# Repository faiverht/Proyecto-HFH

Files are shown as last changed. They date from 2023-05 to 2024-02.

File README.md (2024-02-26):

# Proyecto-HFH

## Avance placa primera versión:
Tarjeta de expansión de puertos análogos con conversor análogo digital MCP3424 (4 canales de 18 bits, PGA:1, 2, 4, 8), comunicación I2C dirección I2C (default): 1101

## Frontal
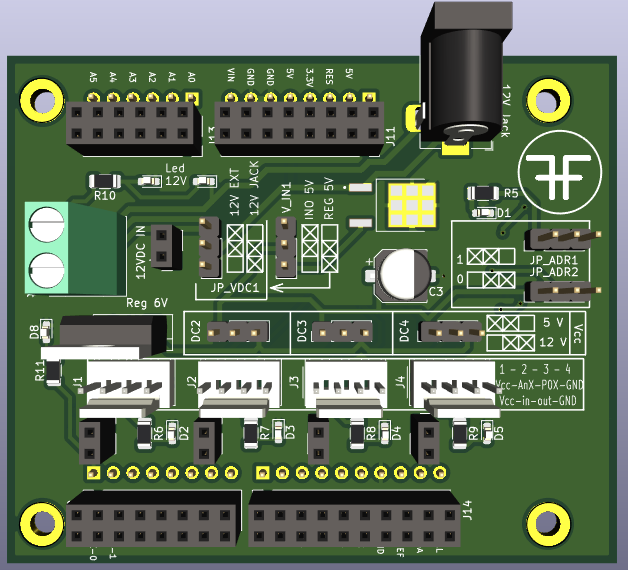
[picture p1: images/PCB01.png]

## Trasera
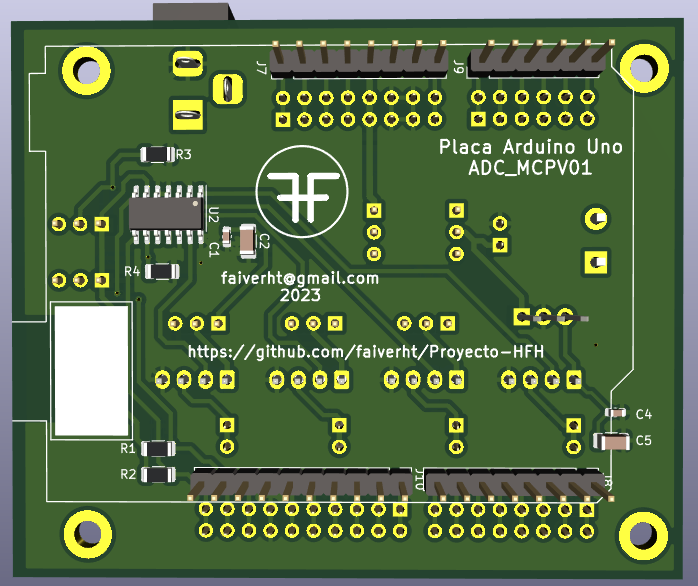
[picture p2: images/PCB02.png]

## Otras
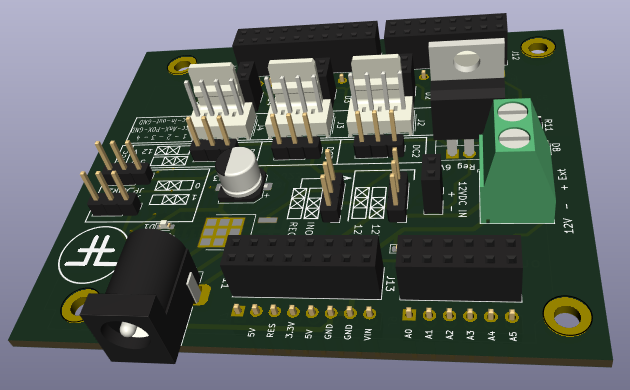
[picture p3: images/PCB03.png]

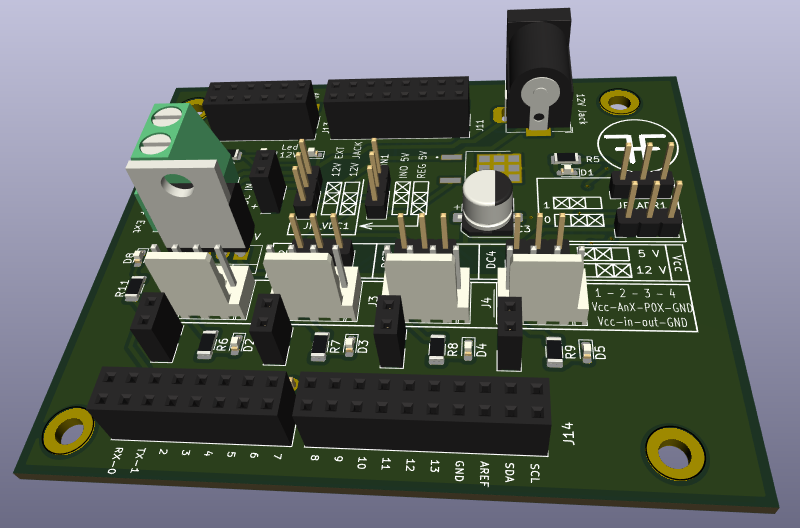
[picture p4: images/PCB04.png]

## Terminado
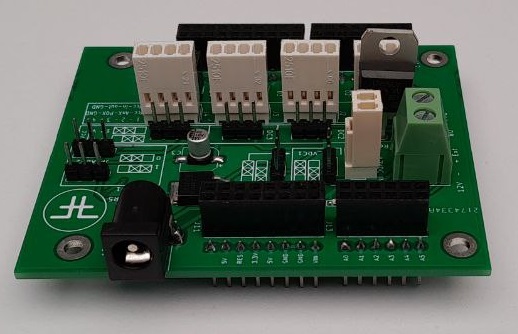
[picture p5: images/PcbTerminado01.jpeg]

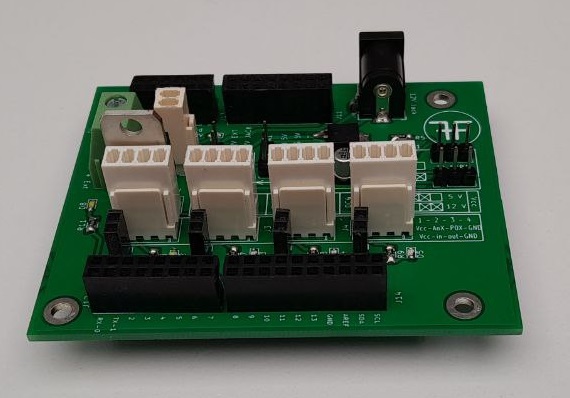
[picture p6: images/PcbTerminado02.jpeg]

## Configuración de Jumpers para fuente de alimetación

Alimentación de voltaje configurable:

1 - Desde la placa arduino Uno 5V (Jumper JP_VDC1 cualquiera o sin conexión y jumper V_IN1 en posición 'INO 5V')

2 - Desde fuente externa mediante Jack 12V (Jumper JP_VDC1  en posición '12V JACK' y jumper V_IN1 en posición 'REG 5V')

3 - Desde fuente externa mediante bornera 12V (Jumper JP_VDC1  en posición '12V EXT' y jumper V_IN1 en posición 'REG 5V')

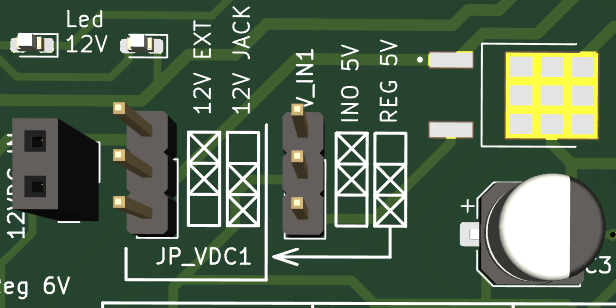
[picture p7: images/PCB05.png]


Adicionalmente los conectores J2, J3 y J4 tienen alimentación configurable de 5V o 12V según posición de los jumpers DC2, DC3 y DC4

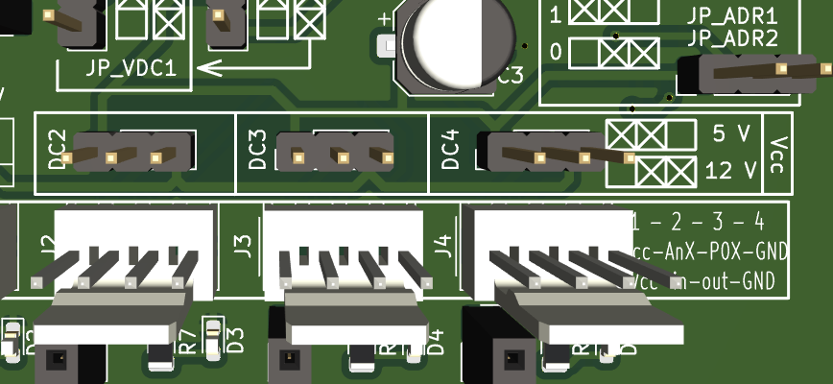
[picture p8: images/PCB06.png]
Jumpers DC 5 - 12 V


**Nota:**

El conector J1 se utiliza exclusivamente para sensor de entrada con alimentación de 6V

## Tarjeta de expansión terminada y en funcionamiento
EL código de prueba para Arduino se encuentran disponibles en /Arduino/Code pruebas de este mismo repositorio

Arduino y tarjeta de expansión

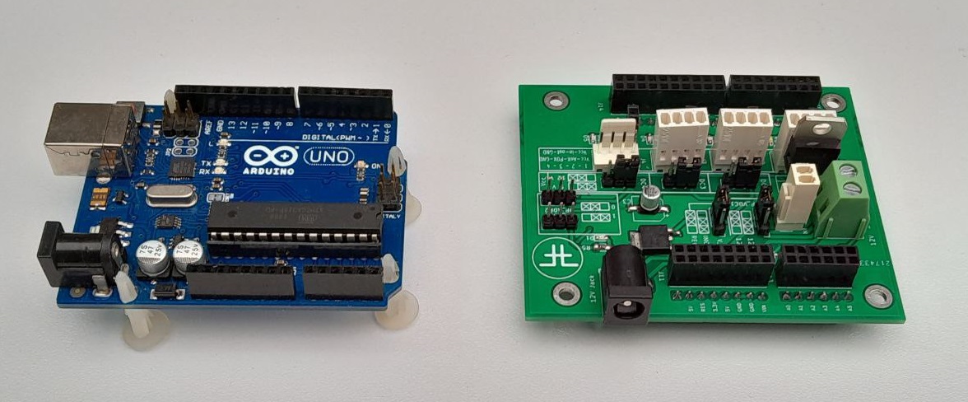
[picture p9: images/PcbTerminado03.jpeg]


Montajes
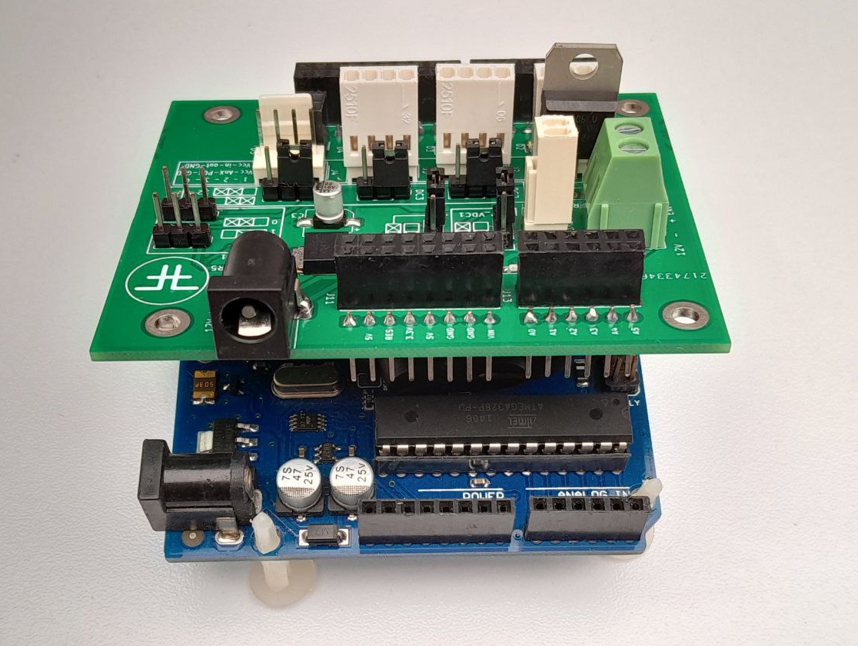
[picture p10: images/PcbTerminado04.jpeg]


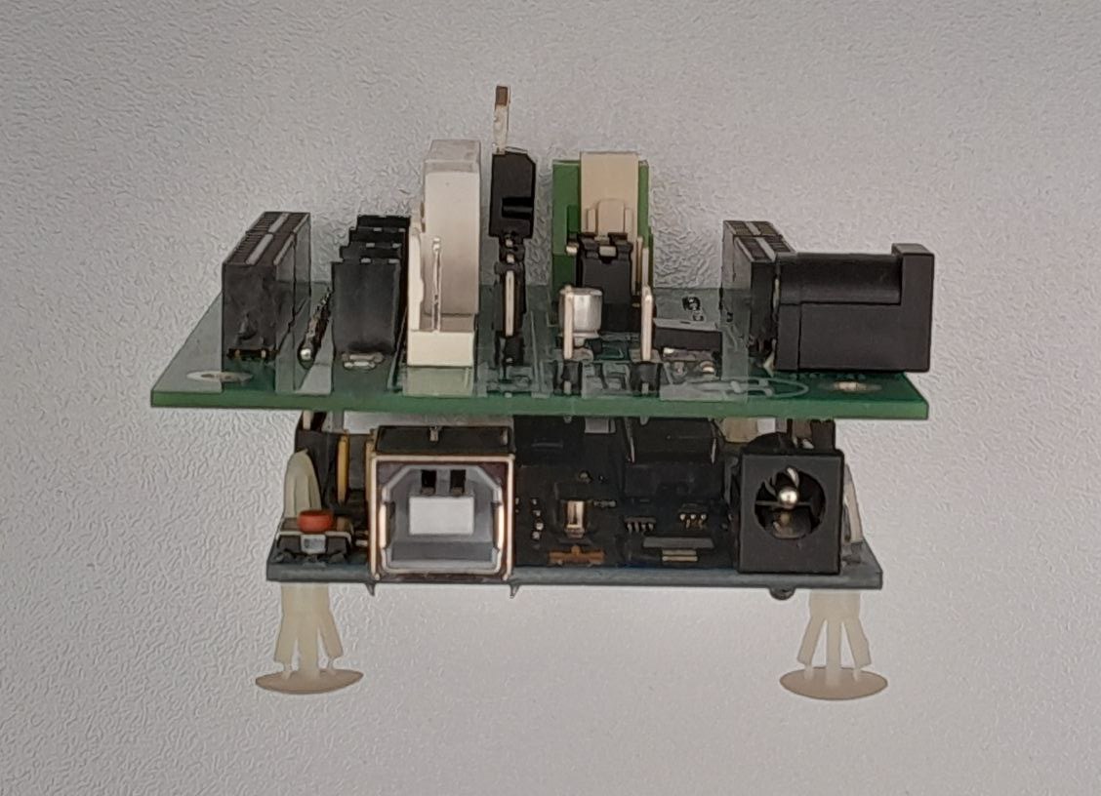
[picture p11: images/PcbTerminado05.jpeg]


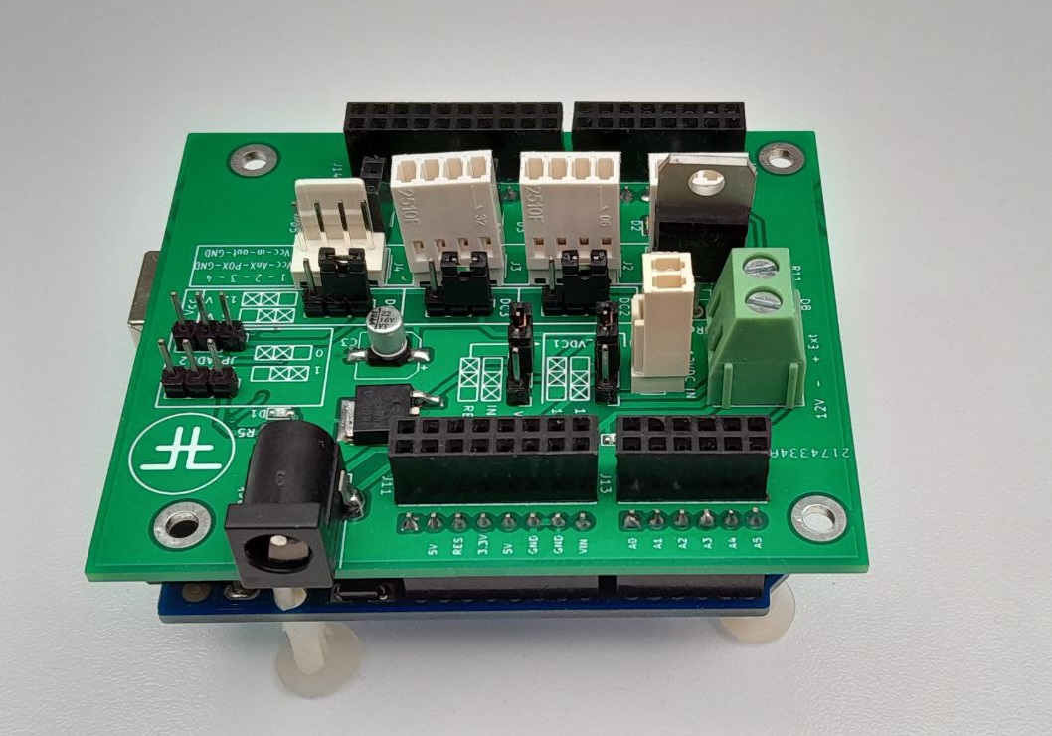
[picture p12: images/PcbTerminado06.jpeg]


Prueba de montaje y adquisición con sensor de gas MQ4

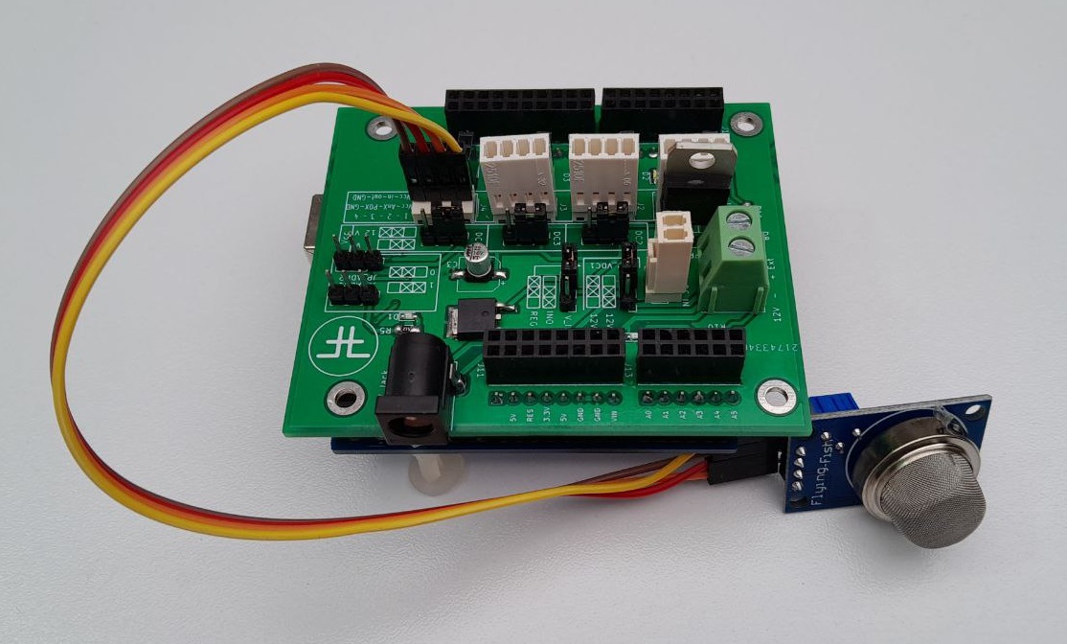
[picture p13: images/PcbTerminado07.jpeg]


## Proyecto de monitoreo y control con Arduino y/o Raspberry Pi y/o PC (Win - Linux)

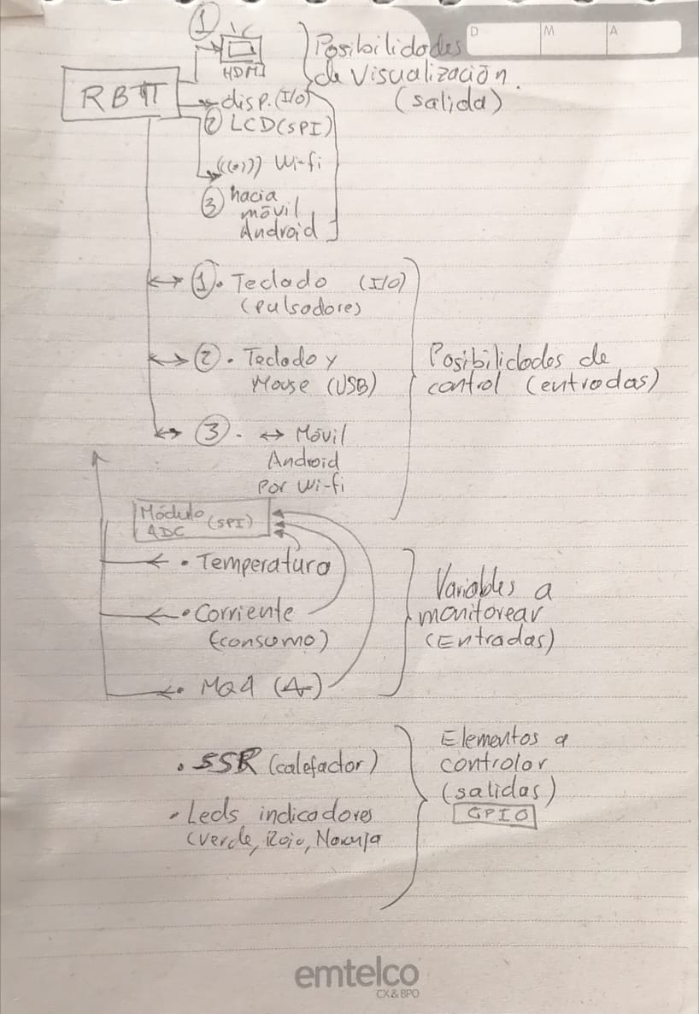
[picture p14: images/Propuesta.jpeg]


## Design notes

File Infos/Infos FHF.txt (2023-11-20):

****************************************************************
https://pypi.org/project/pcf8574-io/

import pcf8574_io

paquete para raspberry para manejar el adaptador I2C a paralelo con el LCD 2X16

****************************************************************
https://www.prometec.net/bus-i2c/

tutorial I2C y LCD para auduino

****************************************************************
https://www.sensingthecity.com/configuring-an-mq-4-sensor-to-detect-methane-gas/

Prueba básica de sensor MQ4 con Arduino

****************************************************************
Se adiciona proyecto en KiCad
Version: 7.99.0-2684-g11de95778b, release build

* ADC_MCPV01.kicad_pro
* ADC_MCPV01.kicad_sch
* ADC_MCPV01.kicad_pcb

****************************************************************

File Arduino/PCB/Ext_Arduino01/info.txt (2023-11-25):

Application: KiCad x64 on x64

Version: 7.99.0-2684-g11de95778b, release build

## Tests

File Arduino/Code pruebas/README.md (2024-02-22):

# Prueba 01

## Escaneo para detectar y/o confirmar la dirección del dispositivo:

Código para el escaneo de dispositivos conectados al bus I2C

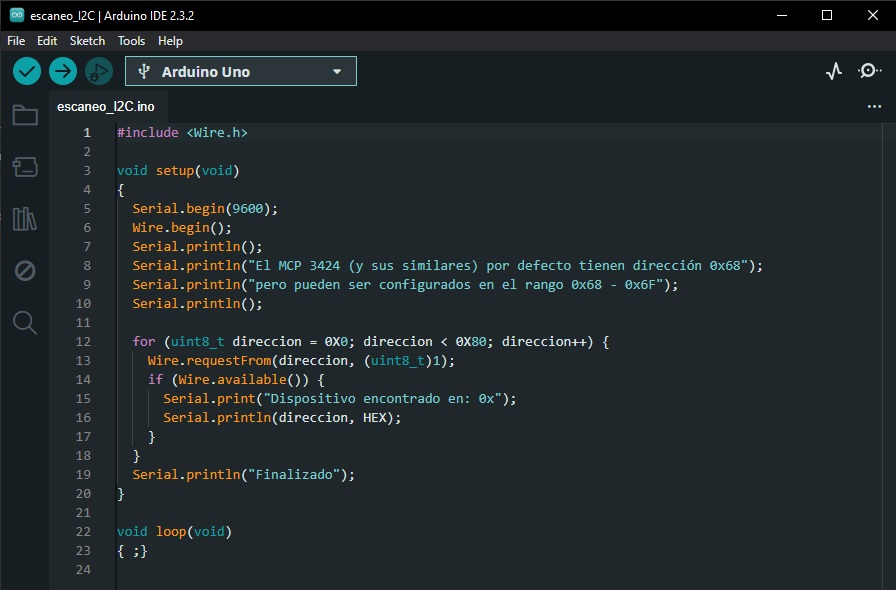
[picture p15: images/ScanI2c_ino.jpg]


Respuesta obtenida del escaneo y visualizada en el monitor serial de Arduino

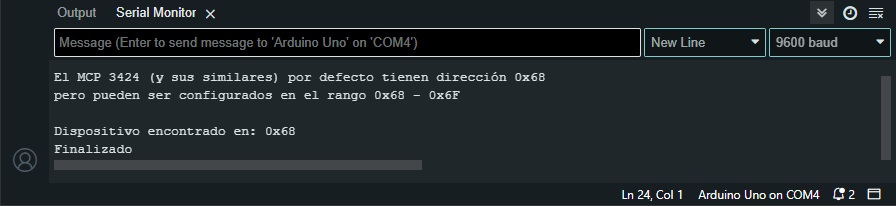
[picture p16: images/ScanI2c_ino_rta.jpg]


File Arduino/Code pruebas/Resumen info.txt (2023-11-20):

****************************************************************
I2C_scan.ino - Ok

Escanea dispositivos I2C conectados al bus

Para tarjeta de conversión I2C a bus paralelo LCD se encuentra dirección en 0x27

****************************************************************
NTC_geek_01.ino.ino - Ok

Se lee el puerto A0 a 10 bits con conversión a Temp, basado en termistor NTC

****************************************************************
LCD_01.ino - Ok

Prueba básica de pantalla LCD con comunicación I2C
NOTA: Se debe incluir la biblioteca para compilar el proyecto
Sketch >> Incluir biblioteca >> Añadir biblioteca .ZIP...
allí se debe seleccionar el archivo descargado de la biblioteca correspondiente

****************************************************************
LCD_02_ADC.ino - Ok

Se visualiza lectura del ADC 'A0' a 10 bits.

╔══════════════════════════════════════════════════════════════╗
║ Pendiente: Se debe revisar la impresión de texto + variable  ║
║ con formato												   ║
╚══════════════════════════════════════════════════════════════╝

****************************************************************
LCD_03_MQ4.ino - Ok

Se visualiza lectura del ADC 'A0' a 10 bits. Solamente se visualiza el valor de lectura de voltaje generado, falta la escala en ppm

╔═══════════════════════════════════════════════════════════════╗
║ Pendiente: Se debe aplicar escalamiento de voltaje a ppm	║
╚═══════════════════════════════════════════════════════════════╝

****************************************************************
LCD_03_MQ4_ppm.ino

Por ahora similar a LCD_03_MQ4.ino

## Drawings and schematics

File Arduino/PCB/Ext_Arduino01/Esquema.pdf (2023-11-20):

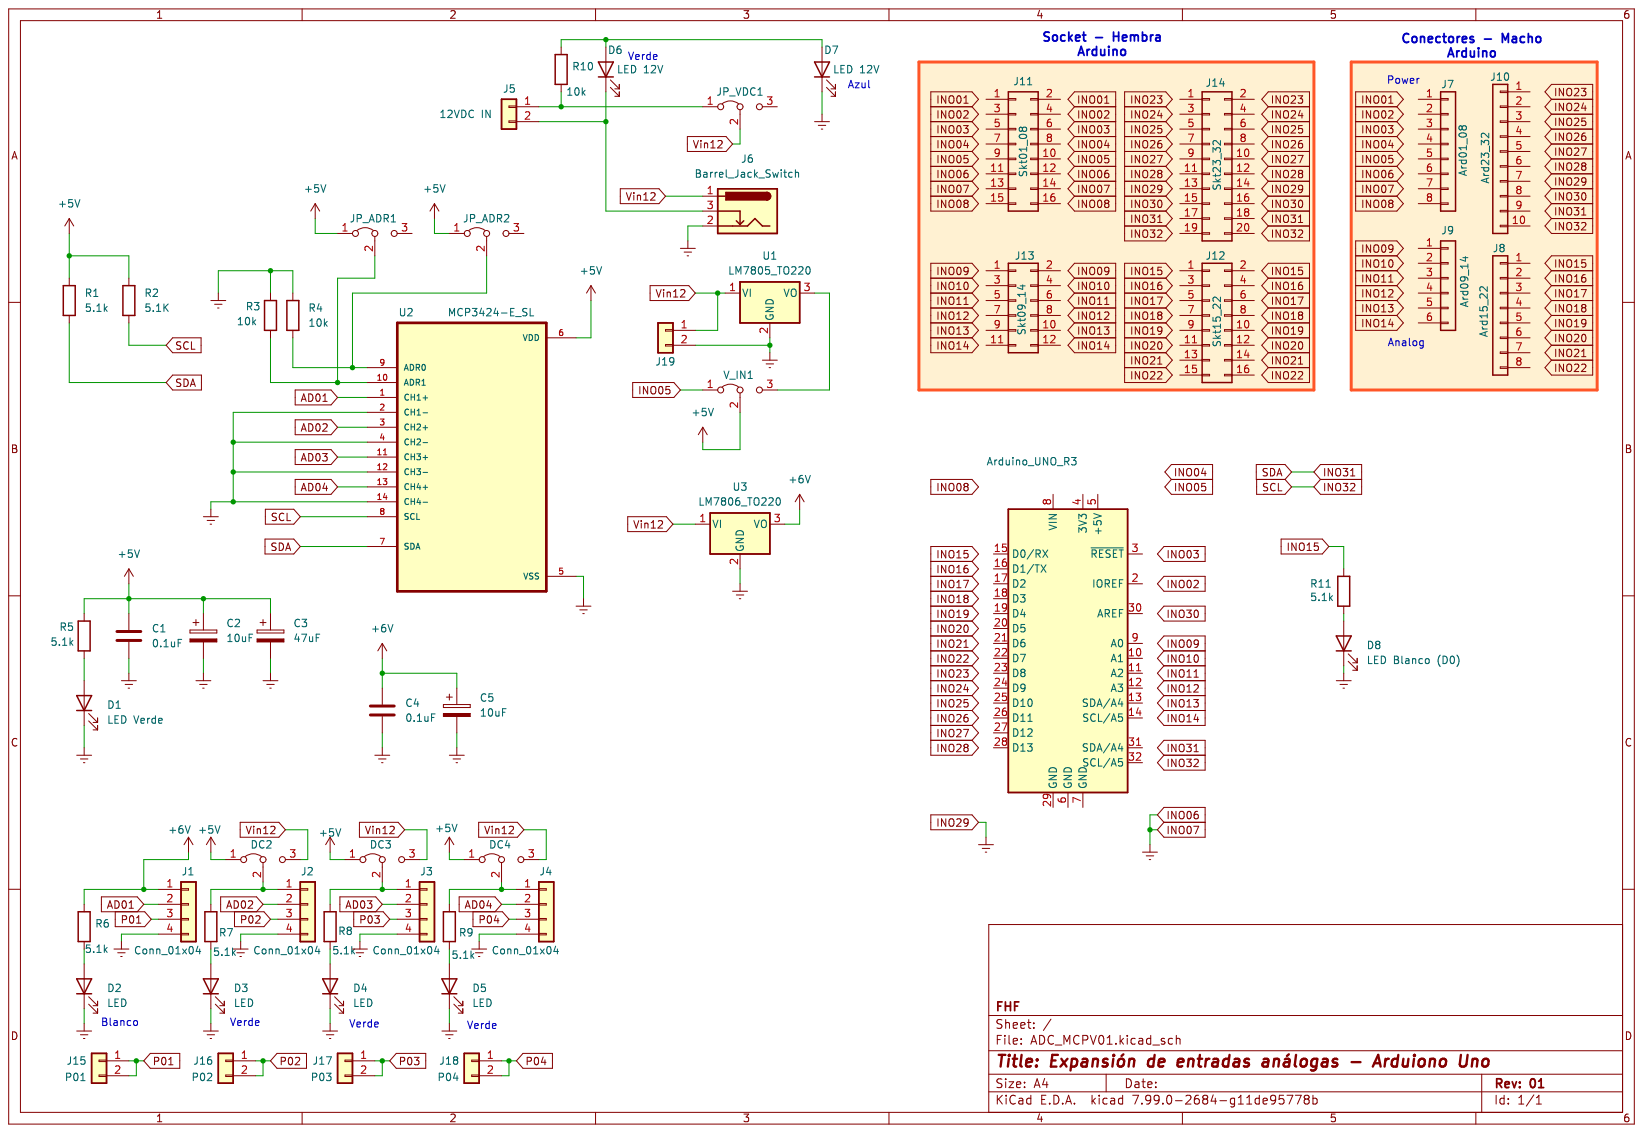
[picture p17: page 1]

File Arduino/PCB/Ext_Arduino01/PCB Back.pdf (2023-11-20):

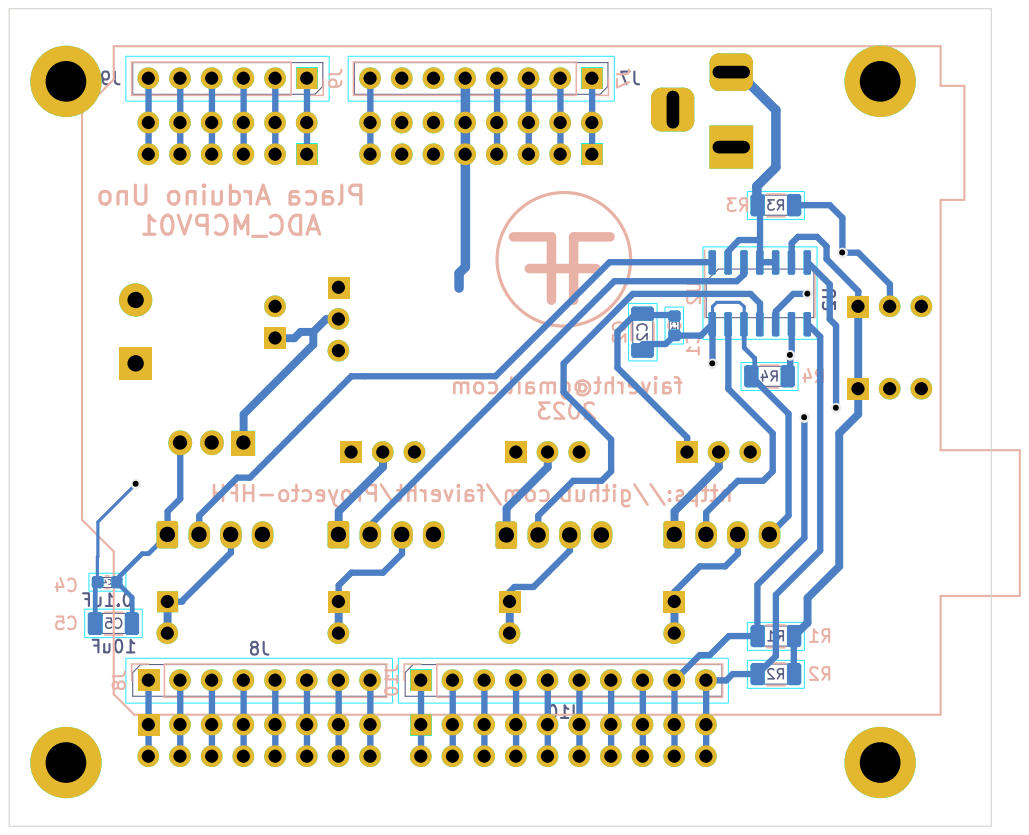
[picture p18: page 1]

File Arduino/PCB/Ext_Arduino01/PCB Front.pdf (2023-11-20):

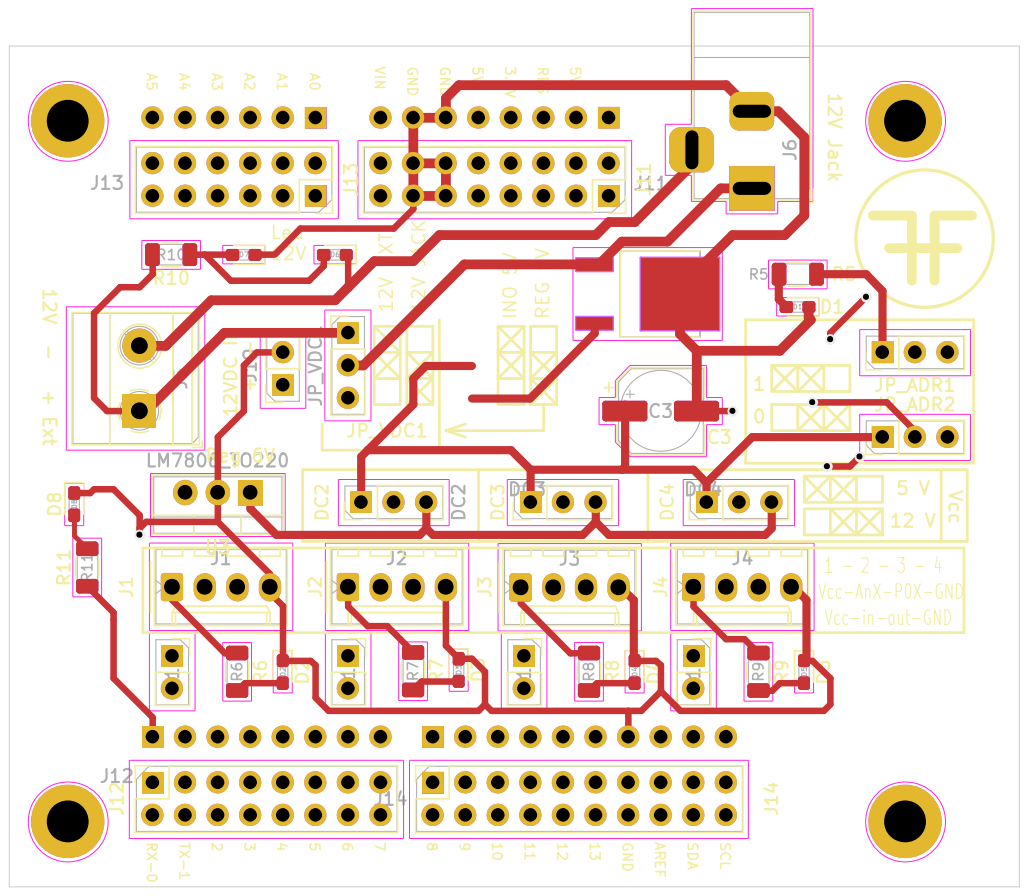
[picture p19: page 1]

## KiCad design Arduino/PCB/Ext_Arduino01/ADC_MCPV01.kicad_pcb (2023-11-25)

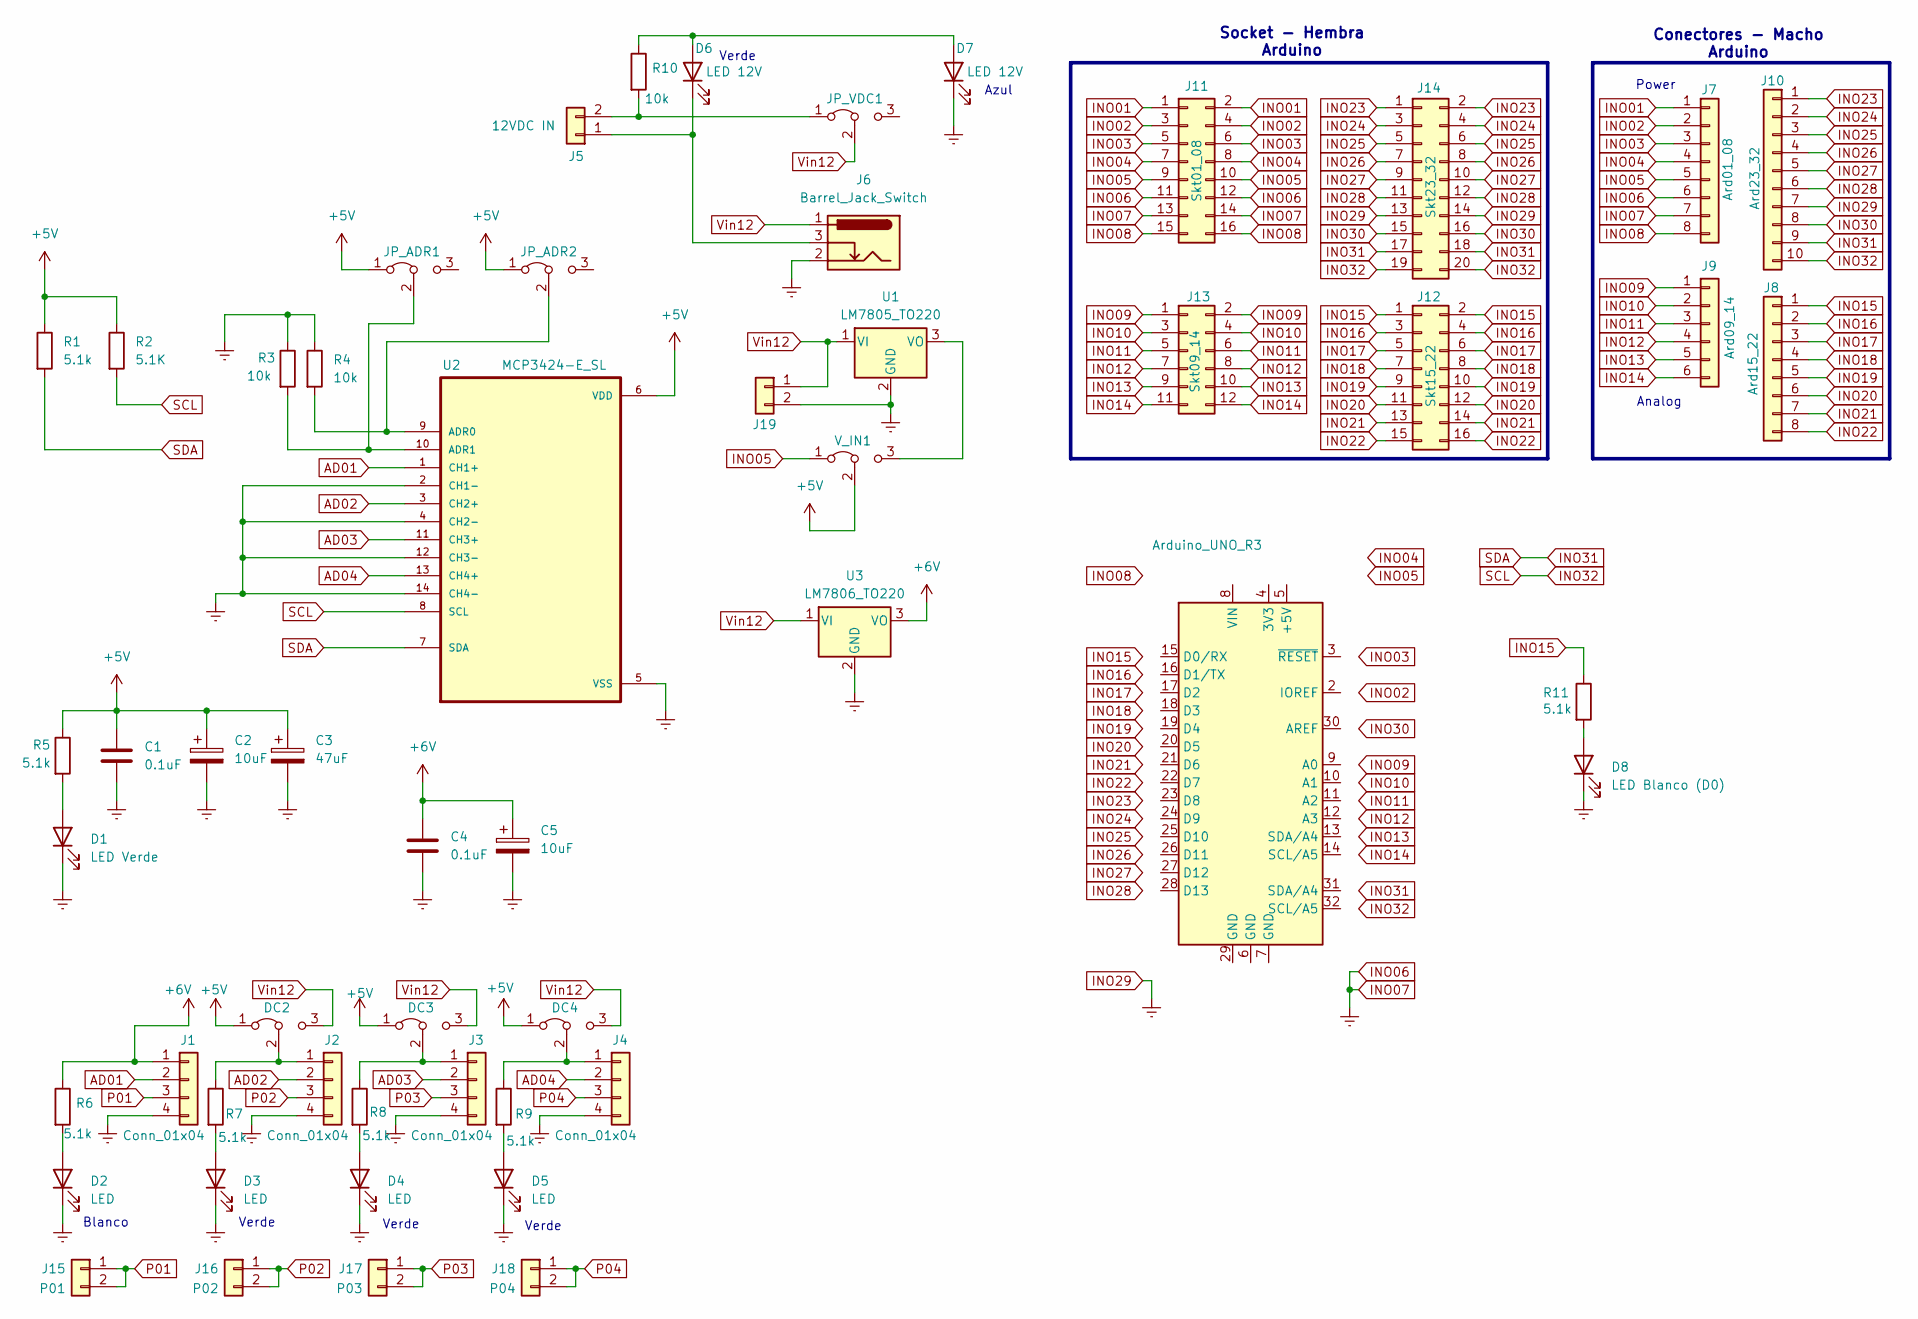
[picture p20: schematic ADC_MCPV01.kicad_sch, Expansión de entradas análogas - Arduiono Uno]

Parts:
A1: Arduino_UNO_R3
C1, C4: 0.1uF; C_0603_1608Metric
C2, C5: 10uF; C_1206_3216Metric
C3: 47uF; CP_Elec_6.3x5.9
D1: LED Verde; LED_0603_1608Metric_Pad1.05x0.95mm_HandSolder
D2, D3, D4, D5: LED; LED_0603_1608Metric_Pad1.05x0.95mm_HandSolder
D6, D7: LED 12V; LED_0603_1608Metric_Pad1.05x0.95mm_HandSolder
D8: LED Blanco (D0); LED_0603_1608Metric_Pad1.05x0.95mm_HandSolder
DC2, DC3, DC4: Jumper_3_Bridged12; PinHeader_1x03_P2.54mm_Vertical
J1, J2, J3, J4: Conn_01x04; Molex_KK-254_AE-6410-04A_1x04_P2.54mm_Vertical
J5: 12VDC IN; TerminalBlock_Phoenix_MKDS-1,5-2-5.08_1x02_P5.08mm_Horizont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
J6: Barrel_Jack_Switch; BarrelJack_Horizontal
J7: Ard01_08; PinHeader_1x08_P2.54mm_Vertical
J8: Ard15_22; PinHeader_1x08_P2.54mm_Vertical
J9: Ard09_14; PinHeader_1x06_P2.54mm_Vertical
J10: Ard23_32; PinHeader_1x10_P2.54mm_Vertical
J11: Skt01_08; PinSocket_2x08_P2.54mm_Vertical
J12: Skt15_22; PinSocket_2x08_P2.54mm_Vertical
J13: Skt09_14; PinSocket_2x06_P2.54mm_Vertical
J14: Skt23_32; PinSocket_2x10_P2.54mm_Vertical
J15: P01; PinSocket_1x02_P2.54mm_Vertical
J16: P02; PinSocket_1x02_P2.54mm_Vertical
J17: P03; PinSocket_1x02_P2.54mm_Vertical
J18: P04; PinSocket_1x02_P2.54mm_Vertical
J19: 12VDC IN; PinSocket_1x02_P2.54mm_Vertical
JP_ADR1, JP_ADR2: Jumper_3_Bridged12; PinHeader_1x03_P2.54mm_Vertical
JP_VDC1: Jumper_3_Bridged12; PinHeader_1x03_P2.54mm_Vertical
R1, R5, R6, R7, R8, R9, R11: 5.1k; R_1206_3216Metric
R2: 5.1K; R_1206_3216Metric
R3, R4, R10: 10k; R_1206_3216Metric
U1: LM7805_TO220; TO229P990X238-3N
U2: MCP3424-E_SL; SOIC-14_3.9x8.7mm_P1.27mm; DigiKey_Part_Number MCP3424-E/SL-ND
U3: LM7806_TO220; TO-220-3_Vertical
V_IN1: Jumper_3_Bridged12; PinHeader_1x03_P2.54mm_Vertical

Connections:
+5V: C1.1, C2.1, C3.1, DC2.1 (A), DC3.1 (A), DC4.1 (A), JP_ADR1.1 (A), JP_ADR2.1 (A), R1.1, R2.1, R5.1, U2.6 (VDD), V_IN1.2 (C)
+6V: C4.1, C5.1, J1.1, R6.1, U3.3 (VO)
AD01: J1.2, U2.1 (CH1+)
AD02: J2.2, U2.3 (CH2+)
AD03: J3.2, U2.11 (CH3+)
AD04: J4.2, U2.13 (CH4+)
INO01: J7.1, J11.1, J11.2
INO02: J7.2, J11.3, J11.4
INO03: J7.3, J11.5, J11.6
INO04: J7.4, J11.7, J11.8
INO05: J7.5, J11.9, J11.10, V_IN1.1 (A)
INO06: C1.2, C2.2, C3.2, C4.2, C5.2, D1.1 (K), D2.1 (K), D3.1 (K), D4.1 (K), D5.1 (K), D7.1 (K), D8.1 (K), J1.4, J2.4, J3.4, J4.4, J6.2, J7.6, J7.7, J10.7, J11.11, J11.12, J11.13, J11.14, J14.13, J14.14, J19.2, R3.1, R4.1, U1.2 (GND), U2.2 (CH1-), U2.4 (CH2-), U2.5 (VSS), U2.12 (CH3-), U2.14 (CH4-), U3.2 (GND)
INO08: J7.8, J11.15, J11.16
INO09: J9.1, J13.1, J13.2
INO10: J9.2, J13.3, J13.4
INO11: J9.3, J13.5, J13.6
INO12: J9.4, J13.7, J13.8
INO13: J9.5, J13.9, J13.10
INO14: J9.6, J13.11, J13.12
INO15: J8.1, J12.1, J12.2, R11.1
INO16: J8.2, J12.3, J12.4
INO17: J8.3, J12.5, J12.6
INO18: J8.4, J12.7, J12.8
INO19: J8.5, J12.9, J12.10
INO20: J8.6, J12.11, J12.12
INO21: J8.7, J12.13, J12.14
INO22: J8.8, J12.15, J12.16
INO23: J10.1, J14.1, J14.2
INO24: J10.2, J14.3, J14.4
INO25: J10.3, J14.5, J14.6
INO26: J10.4, J14.7, J14.8
INO27: J10.5, J14.9, J14.10
INO28: J10.6, J14.11, J14.12
INO30: J10.8, J14.15, J14.16
INO31: J10.9, J14.17, J14.18, R1.2, U2.7 (SDA)
INO32: J10.10, J14.19, J14.20, R2.2, U2.8 (SCL)
unnamed: D1.2 (A), R5.2
unnamed: D2.2 (A), R6.2
unnamed: D3.2 (A), R7.2
unnamed: D4.2 (A), R8.2
unnamed: D5.2 (A), R9.2
unnamed: D6.2 (A), D7.2 (A), R10.1
unnamed: D6.1 (K), J5.1, J6.3
unnamed: D8.2 (A), R11.2
unnamed: DC2.2 (C), J2.1, R7.1
unnamed: DC3.2 (C), J3.1, R8.1
unnamed: DC4.2 (C), J4.1, R9.1
unnamed: J5.2, JP_VDC1.1 (A), R10.2
unnamed: JP_ADR1.2 (C), R3.2, U2.10 (ADR1)
unnamed: JP_ADR2.2 (C), R4.2, U2.9 (ADR0)
unnamed: U1.3 (VO), V_IN1.3 (B)
P01: J1.3, J15.1, J15.2
P02: J2.3, J16.1, J16.2
P03: J3.3, J17.1, J17.2
P04: J4.3, J18.1, J18.2
Vin12: DC2.3 (B), DC3.3 (B), DC4.3 (B), J6.1, J19.1, JP_VDC1.2 (C), U1.1 (VI), U3.1 (VI)

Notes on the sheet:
Analog
Verde
Blanco
Azul
Power
Socket - Hembra Arduino
Conectores - Macho Arduino

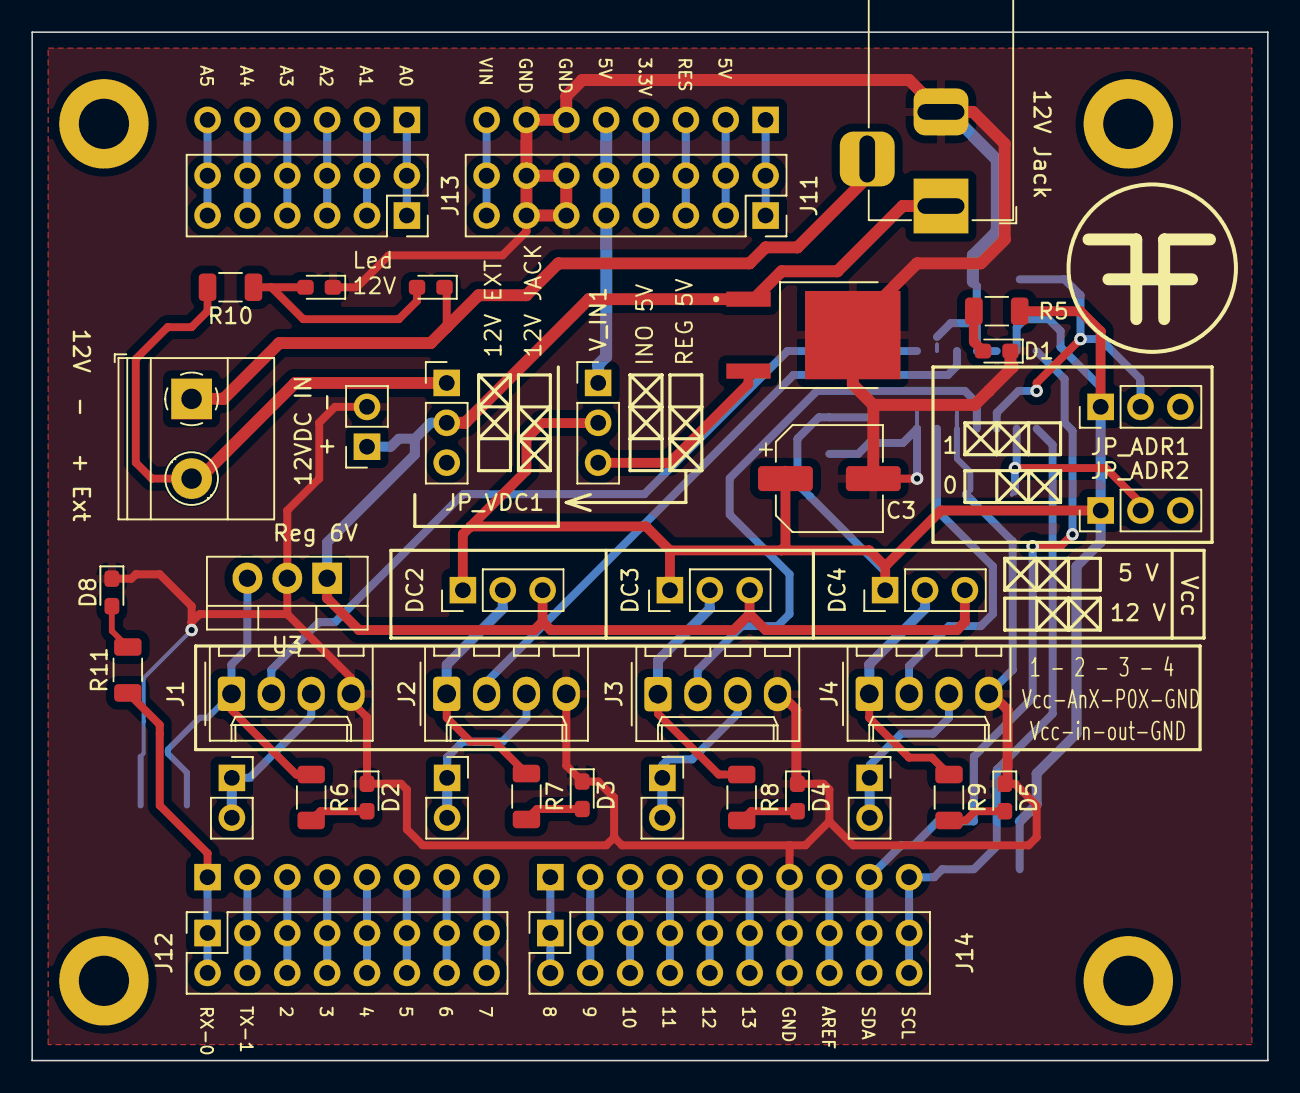
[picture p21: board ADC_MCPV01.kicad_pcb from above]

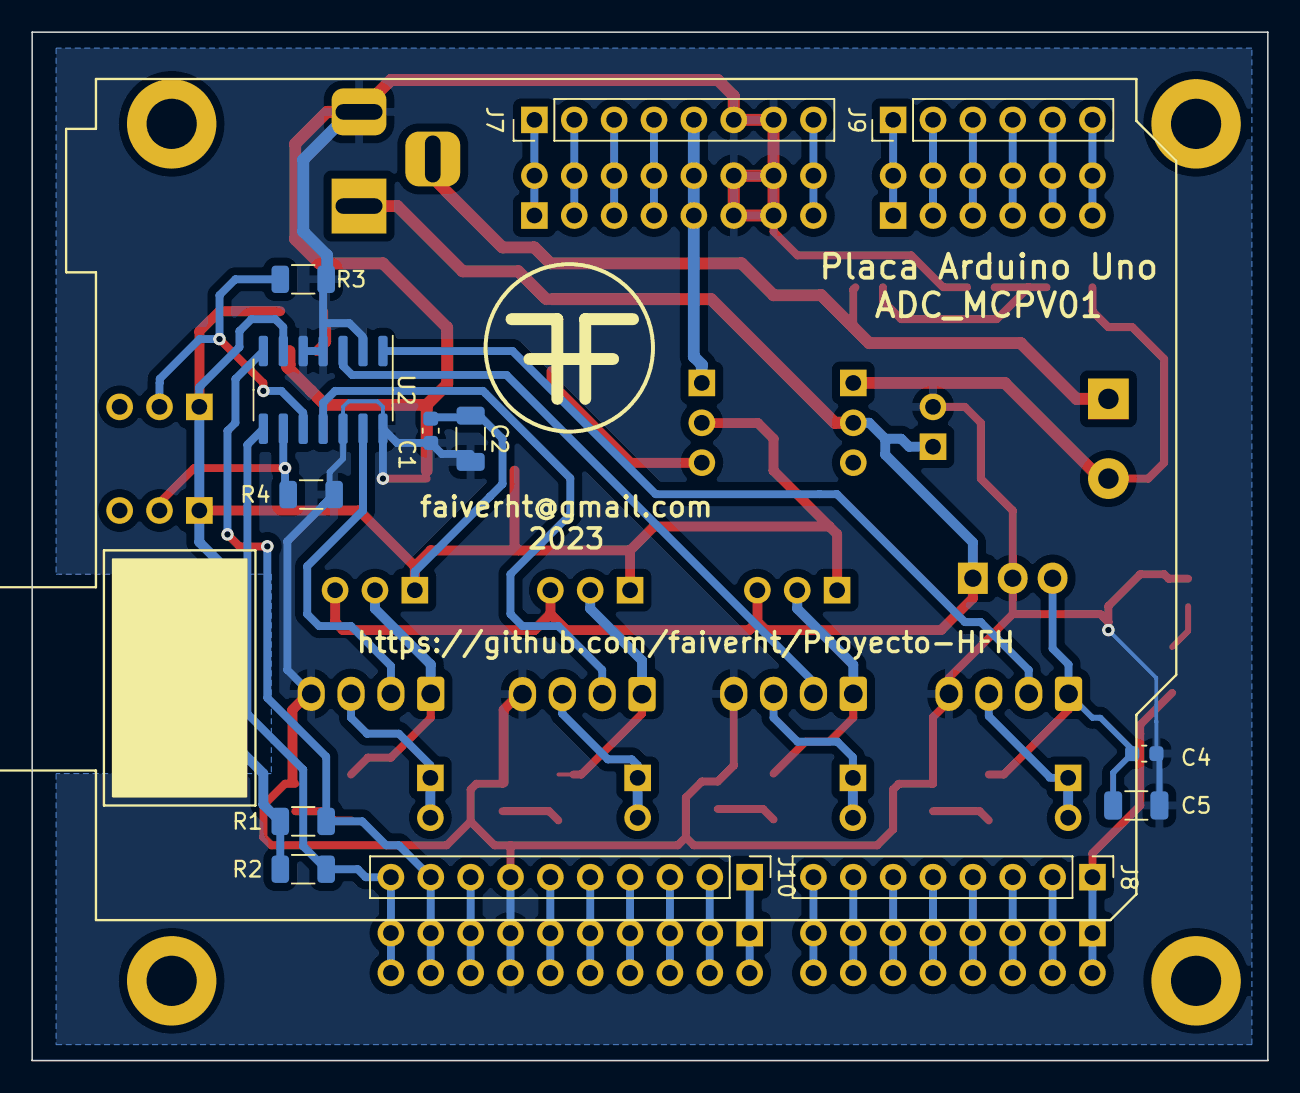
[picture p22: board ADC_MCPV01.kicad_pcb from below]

Board: 2 copper layers, 78.7 x 65.5 mm, 53 parts (13 on the bottom side), 56 nets.

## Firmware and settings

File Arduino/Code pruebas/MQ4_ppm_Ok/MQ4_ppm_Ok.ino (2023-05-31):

/**************************************************************************** 
  Author : Andy @ MYBOTIC www.mybotic.com.my
  Date:5/7/2016 
  Project: How to detect the concentration of gas by using MQ2 sensor
****************************************************************************/


/************************Hardware Related Macros************************************/
#include <Wire.h>
#include <LCD.h>
#include <LiquidCrystal_I2C.h>

#define I2C_ADDR    0x27  // Dirección del dispositivo I2C (LCD)

const int calibrationLed = 13;                      //when the calibration start , LED pin 13 will light up , off when finish calibrating
const int MQ_PIN=A0;                                //define which analog input channel you are going to use
int RL_VALUE=1;                                     //define the load resistance on the board, in kilo ohms
float RO_CLEAN_AIR_FACTOR=4.3;                     //RO_CLEAR_AIR_FACTOR=(Sensor resistance in clean air)/RO,
                                                    //which is derived from the chart in datasheet
 
/***********************Software Related Macros************************************/
int CALIBARAION_SAMPLE_TIMES=50;                    //define how many samples you are going to take in the calibration phase
int CALIBRATION_SAMPLE_INTERVAL=500;                //define the time interal(in milisecond) between each samples in the
                                                    //cablibration phase
int READ_SAMPLE_INTERVAL=50;                        //define how many samples you are going to take in normal operation
int READ_SAMPLE_TIMES=5;                            //define the time interal(in milisecond) between each samples in 
                                                    //normal operation
 
/**********************Application Related Macros**********************************/
#define         GAS_LPG             0   
#define         GAS_CO              1   
#define         GAS_SMOKE           2    
 
/*****************************Globals***********************************************/
float           MQ4_FH_CH4[3]  =  {2.3,0.24,-0.32};
float           LPGCurve[3]  =  {2.3,0.21,-0.47};   //two points are taken from the curve. 
                                                    //with these two points, a line is formed which is "approximately equivalent"
                                                    //to the original curve. 
                                                    //data format:{ x, y, slope}; point1: (lg200, 0.21), point2: (lg10000, -0.59) 

float           COCurve[3]  =  {2.3,0.72,-0.34};    //two points are taken from the curve. 
                                                    //with these two points, a line is formed which is "approximately equivalent" 
                                                    //to the original curve.
                                                    //data format:{ x, y, slope}; point1: (lg200, 0.72), point2: (lg10000,  0.15) 
float           SmokeCurve[3] ={2.3,0.53,-0.44};    //two points are taken from the curve. 
                                                    //with these two points, a line is formed which is "approximately equivalent" 
                                                    //to the original curve.
                                                    //data format:{ x, y, slope}; point1: (lg200, 0.53), point2: (lg10000,  -0.22)                                                     
float           Ro           =  10;                 //Ro is initialized to 10 kilo ohms

//LiquidCrystal lcd(12, 11, 5, 4, 3 ,2 );           //LCD pins
LiquidCrystal_I2C             lcd(I2C_ADDR,2, 1, 0, 4, 5, 6, 7);

void setup()
{ 
  
  lcd.begin(16,2);
  lcd.setBacklightPin(3,POSITIVE);
  lcd.setBacklight(HIGH);
  pinMode(calibrationLed,OUTPUT);
  digitalWrite(calibrationLed,HIGH);
  lcd.print("Calibrating...");                        //LCD display

  
  Ro = MQCalibration(MQ_PIN);                         //Calibrating the sensor. Please make sure the sensor is in clean air         
  digitalWrite(calibrationLed,LOW);              
  
  lcd.print("done!");                                 //LCD display
  lcd.setCursor(0,1);
  lcd.print("Ro= ");
  lcd.print(Ro);
  lcd.print("kohm");
  delay(3000);
}
 
void loop()
{  
  long iPPM_LPG = 0;
  long iPPM_CO = 0;
  long iPPM_Smoke = 0;

  iPPM_LPG = MQGetGasPercentage(MQRead(MQ_PIN)/Ro,GAS_LPG);
  //iPPM_CO = MQGetGasPercentage(MQRead(MQ_PIN)/Ro,GAS_CO);
  //iPPM_Smoke = MQGetGasPercentage(MQRead(MQ_PIN)/Ro,GAS_SMOKE);
  
   lcd.clear();   
   lcd.setCursor( 0 , 0 );
   lcd.print("ppm gas ");
   
   lcd.setCursor( 0 , 1 );
   lcd.print("Gas: ");
   lcd.print(iPPM_LPG);
   lcd.print(" ppm");   
   /*
   lcd.setCursor( 0, 2 );
   lcd.print("CO: ");
   lcd.print(iPPM_CO);
   lcd.print(" ppm");    

   lcd.setCursor( 0,3 );
   lcd.print("Smoke: ");
   lcd.print(iPPM_Smoke);
   lcd.print(" ppm");  */

   delay(200);
  
}
 
/****************** MQResistanceCalculation ****************************************
Input:   raw_adc - raw value read from adc, which represents the voltage
Output:  the calculated sensor resistance
Remarks: The sensor and the load resistor forms a voltage divider. Given the voltage
         across the load resistor and its resistance, the resistance of the sensor
         could be derived.
************************************************************************************/ 
float MQResistanceCalculation(int raw_adc)
{
  return ( ((float)RL_VALUE*(1023-raw_adc)/raw_adc));
}
 
/***************************** MQCalibration ****************************************
Input:   mq_pin - analog channel
Output:  Ro of the sensor
Remarks: This function assumes that the sensor is in clean air. It use  
         MQResistanceCalculation to calculates the sensor resistance in clean air 
         and then divides it with RO_CLEAN_AIR_FACTOR. RO_CLEAN_AIR_FACTOR is about 
         10, which differs slightly between different sensors.
************************************************************************************/ 
float MQCalibration(int mq_pin)
{
  int i;
  float val=0;

  for (i=0;i<CALIBARAION_SAMPLE_TIMES;i++) {            //take multiple samples
    val += MQResistanceCalculation(analogRead(mq_pin));
    delay(CALIBRATION_SAMPLE_INTERVAL);
  }
  val = val/CALIBARAION_SAMPLE_TIMES;                   //calculate the average value
  val = val/RO_CLEAN_AIR_FACTOR;                        //divided by RO_CLEAN_AIR_FACTOR yields the Ro                                        
  return val;                                                      //according to the chart in the datasheet 

}
 
/*****************************  MQRead *********************************************
Input:   mq_pin - analog channel
Output:  Rs of the sensor
Remarks: This function use MQResistanceCalculation to caculate the sensor resistenc (Rs).
         The Rs changes as the sensor is in the different consentration of the target
         gas. The sample times and the time interval between samples could be configured
         by changing the definition of the macros.
************************************************************************************/ 
float MQRead(int mq_pin)
{
  int i;
  float rs=0;
 
  for (i=0;i<READ_SAMPLE_TIMES;i++) {
    rs += MQResistanceCalculation(analogRead(mq_pin));
    delay(READ_SAMPLE_INTERVAL);
  }
 
  rs = rs/READ_SAMPLE_TIMES;
 
  return rs;  
}
 
/*****************************  MQGetGasPercentage **********************************
Input:   rs_ro_ratio - Rs divided by Ro
         gas_id      - target gas type
Output:  ppm of the target gas
Remarks: This function passes different curves to the MQGetPercentage function which 
         calculates the ppm (parts per million) of the target gas.
************************************************************************************/ 
long MQGetGasPercentage(float rs_ro_ratio, int gas_id)
{
  if ( gas_id == GAS_LPG ) {
     return MQGetPercentage(rs_ro_ratio,LPGCurve);
  }    
 
  return 0;
}
 
/*****************************  MQGetPercentage **********************************
Input:   rs_ro_ratio - Rs divided by Ro
         pcurve      - pointer to the curve of the target gas
Output:  ppm of the target gas
Remarks: By using the slope and a point of the line. The x(logarithmic value of ppm) 
         of the line could be derived if y(rs_ro_ratio) is provided. As it is a 
         logarithmic coordinate, power of 10 is used to convert the result to non-logarithmic 
         value.
************************************************************************************/ 
long  MQGetPercentage(float rs_ro_ratio, float *pcurve)
{
  return (pow(10,( ((log(rs_ro_ratio)-pcurve[1])/pcurve[2]) + pcurve[0])));
}

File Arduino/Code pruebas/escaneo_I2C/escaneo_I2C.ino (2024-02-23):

#include <Wire.h>

void setup(void)
{
  Serial.begin(9600);
  Wire.begin();
  Serial.println();
  Serial.println("El MCP 3424 (y sus similares) por defecto tienen dirección 0x68");
  Serial.println("pero pueden ser configurados en el rango 0x68 - 0x6F");
  Serial.println();
  
  for (uint8_t direccion = 0X0; direccion < 0X80; direccion++) {
    Wire.requestFrom(direccion, (uint8_t)1);
    if (Wire.available()) {
      Serial.print("Dispositivo encontrado en: 0x");
      Serial.println(direccion, HEX);
    }
  }
  Serial.println("Finalizado");
}

void loop(void)
{ ;}

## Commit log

2023-05-15 Se adiciona archivo de informaciones general del proyecto
    Links, recomendaciones ...
2023-05-15 Resumen de códigos realizados
    Listado, comentarios y recomendaciones acerca de todos los códigos realizados
2023-05-16 LCD_01
    Prueba de funcionamiento LCD con I2C
2023-05-16 LCD_02_ADC
    Visualización en LCD (I2C) de lectura análoga en A0
2023-05-16 LCD_03_MQ4
    Visualización en LCD (I2C) de voltaje análogo (10 bits) capturado desde sensor MQ4
2023-05-31 Create MQ4_ppm_Ok.ino
    Aplicando ecuación según gráficas de datasheet MQ4 paga metano solamente
2023-11-20 Update Infos FHF.txt
    Adicionando proyecto Kicad para Arduino uno
2023-11-20 Add files via upload
    vesión 01
    [ADC_MCPV01.kicad_pcb, ADC_MCPV01.kicad_sch]
2023-11-20 Add files via upload
    Imágenes PCB MCP
2023-11-20 Update README.md
    actualizando imágenes PCB
2023-11-20 Update README.md
    corrigiendo nombre de archivo imágenes sin espacio
2023-11-20 Update README.md
    Actulización de contenido nov20
2023-11-20 Update Resumen info.txt
    correción de forma
2023-11-20 Update Resumen info.txt
    corrección de forma 2
2023-11-20 Add files via upload
    Gerber files
    [ADC_MCPV01-B_Cu.gbr, ADC_MCPV01-B_Mask.gbr, ADC_MCPV01-B_Paste.gbr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]
2023-11-25 actualizando kicad
    [ADC_MCPV01.kicad_pcb, ADC_MCPV01.kicad_sch]
2024-02-22 Add files via upload
    Pcb terminado
2024-02-22 Update README.md
    Adicionando imgs pcb terminado
2024-02-22 Add files via upload
    Subiendo pantallazos de código
